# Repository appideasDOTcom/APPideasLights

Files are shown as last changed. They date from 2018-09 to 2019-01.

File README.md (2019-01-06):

This is code that was written to accompany a custom-built WiFi controller for 5050SMD LED light strips. The Instructable that shows you how to build the hardware is here:
https://www.instructables.com/id/Easier-WiFi-LED-Light-Strip-Controller/
The APPideas article that covers start-to-finish instructions is available here:
https://appideas.com/the-appideas-wifi-controller-for-led-light-strips/

The Instructables article and the writing at APPideas are nearly identical, but are organized differently. The APPideas write-up is more likely to be kept up-to-date.

An Instructables article that covers version 9 (an older version) of the hardware is here:
https://www.instructables.com/id/WiFi-LED-Light-Strip-Controller/

The arduino directory contains code to be uploaded to an ESP8266-12E development board. Directions for loading the Arduino code are available at the links above. If you built hardware version 9 or earlier (anything prior to the "Easier" WiFi controller article), you will need to checkout the Arduino code from the alt/v9Hardware branch. Alternatively, you can manually change the Arduino code to adjust the pin assignments for that version of the PCB.

The resources directory contains the license file, files for CNC routers and 3D printers, and Fritzing, Eagle and Fusion 360 documents. V10 folders contain current files. V9 and previous, as well as Fritzing files are for legacy versions of the hardware.

The mobile-app directory has a React Native project, which produced native code for both Android and iOS.

## Mobile app installation
**Install the current public version from an app store**
The easiest way to install the app is through your device's app store. Here are the links:
Android: https://play.google.com/store/apps/details?id=com.appideas.appideaslights
iOS: https://itunes.apple.com/us/app/appideas-lights/id1440833432?ls=1&mt=8

**Install the latest development version from source code**
This will only work if you have React Native setup for development. Instructions are available here: https://facebook.github.io/react-native/docs/getting-started.html
Once React Native is setup for development, open a terminal and run these commands
```
mkdir app
cd app
git clone https://github.com/appideasDOTcom/APPideasLights.git ./
cd mobile-app/react-native/AppideasLights
npm install
```
To install for iOS, plug your device into your computer and:
```
react-native run-ios
```
To install for Android, plug your device into your computer and:
```
react-native run-android
```
If compiling or installation fails, run the last command again. This is expected behavior for a first build in React Native

## Using the mobile app

If your controller has not been configured to connect to your network, go into your device's WiFi settings and connect to the access point that is created by the ESP. It will begin with "appideas-" After connecting to the access point, open the app. Alternatively, open a web browser and go to http://192.168.4.1:5050/ Supply your network credentials and click CONNECT. Connect your mobile device to your network again, then close and re-open the app. Tap "+" to add a controller by IP address. Once the controller is added, the main screen of the app will have a button showing its IP address. Tap the button to see the controls. To change the name of the controller or to update the IP address, tap the Config button.

## Controlling lights from a web browser

The ESP8266 controller will respond to http requests to the following endpoints:
```
/ - Displays either the screen that allows you to provide WiFi credentials or a notice that you are already connected
/connect - This only accepts POST data from the root node. Nothing useful will be gained by accessing it directly
/network-status - Get the device's network info in a JSON-encoded string
/status - Get the status of each set of lights in a JSON-encoded string
/rollcall - Verify that the device is responding in a known manner
/control - Control a set of lights. Possible GET parameters are: 
p: 'position' Accepts 'first' or 'second'
c: 'color' Accepts 'red' 'green' 'blue' 'white' or 'all'
l: 'level' Accepts any integer between 0 (off) and 100 (100% power)
```

Here's an example call to the controller:
```
http://10.0.42.241:5050/control?p=first&c=red&l=100
```

The feature/patternLoops branch contains two more endpoints that have no access in the app (yet), but if you want to check out that branch and upload the Arduino code to your ESP board, you may also use these endpoints:
```
/multiset - Set the values of all LEDS (red, green, blue and white) with a single network request
/pattern - Run a pattern, such as strobe or color changes on a timer
```

See issue #12 (Programmable patterns) and issue #16 (Save colors).

## Misc

I have written a crap-ton of mobile apps, but this is my first in React Native. It is functional, but not written with best practices. A majority of the items on the Issues list are related to that fact. If you are an experienced React Native developer and wouldn't mind offering a few hours to refactor this code before the codebase grows to be large, that would be awesome. Issue #1 is the core of it all.

Check out part 1 of this Instructable series. It's about making custom PCBs on a CNC router:

https://www.instructables.com/id/Custom-PCBs-on-a-CNC-Router/

If you have a CNC router this will come in handy for making a custom WiFi constroller.

## License

This software is available under a GPLv3 license. A copy of the license is in resources/gpl/

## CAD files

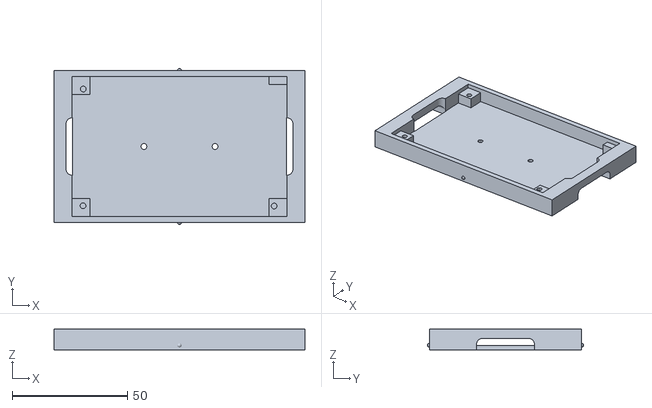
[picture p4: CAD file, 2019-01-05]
resources/3DPrinter/V10/3DPrinter-Electronics_mount_base-V10.stl
108.8 x 67.8 x 9.00

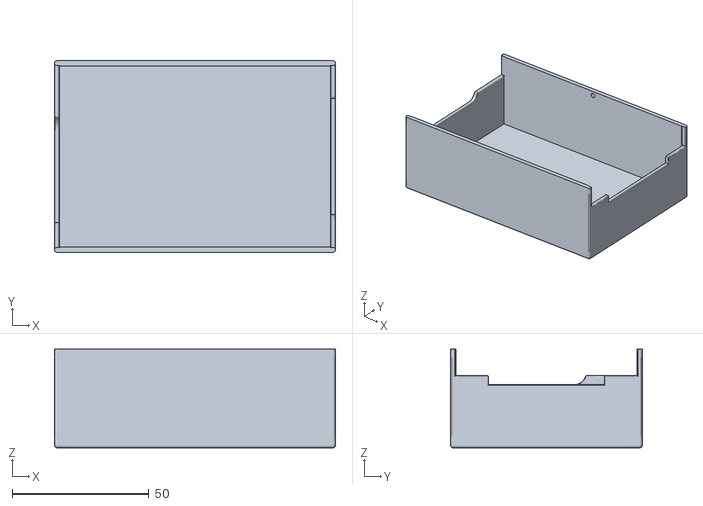
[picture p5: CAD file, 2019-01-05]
resources/3DPrinter/V10/3DPrinter-Electronics_mount_lid-V10.stl
102.6 x 70.0 x 36.1

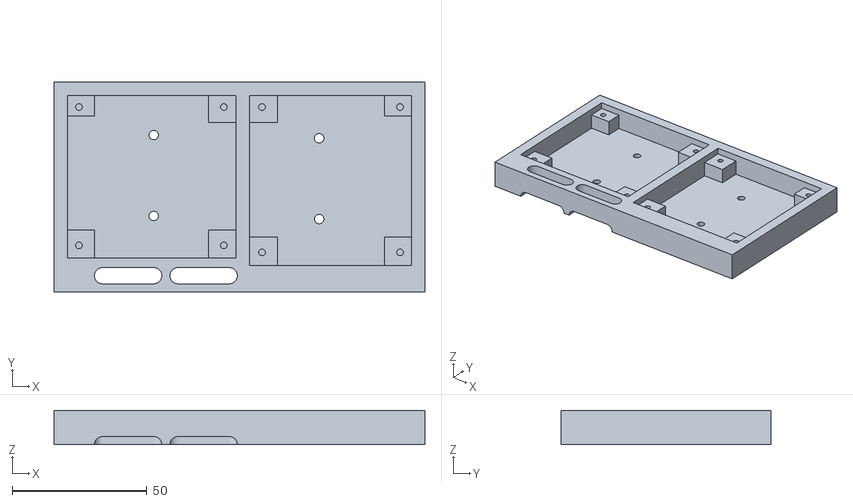
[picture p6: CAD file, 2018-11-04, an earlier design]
resources/3DPrinter/V9/3DPrinter-Electronics_mount-V9.stl
137.6 x 77.8 x 12.7

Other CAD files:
resources/3DPrinter/V10/3DPrinter-Electronics_mount-Fusion360.f3d
resources/3DPrinter/V9/Electronics V9 case.f3d

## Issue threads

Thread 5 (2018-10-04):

Catch network errors

appideasDOTcom, 2018-10-04:
We're not currently wrapping all network calls in try/catch, and there can be app crashes

appideasDOTcom, 2018-10-28:
Fixed with commit 5267d98

Closed 2018-10-28.

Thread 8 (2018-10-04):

Need to detect network state on wake and handle changes

appideasDOTcom, 2018-10-04:
When the app wakes from sleep, it needs to determine whether it is on the 192.168.4.* network and send the user to the appropriate screen

The failure to do so is classified as a bug because switching to/from the private network currently requires for the app to be completely killed and restarted.

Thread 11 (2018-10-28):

Get and set light status on control screen render

appideasDOTcom, 2018-10-28:
When the control screen renders, all the controls are set by default to "all the way on."

An http request to /status will supply a json string with the currently known status of the lights. This should be used to set the controls on initial screen rendering.

appideasDOTcom, 2018-10-29:
Fixed with commit ca2654a

Closed 2018-10-29.

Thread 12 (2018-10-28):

Programmable patterns

appideasDOTcom, 2018-10-28:
There needs to be a way to set a pattern (e.g. changing colors, pulsing, strobe, etc.) on the phone/external device, send the pattern to the controller, and have it continue the pattern without network interactions from the phone/device.

appideasDOTcom, 2018-11-14:
The beginnings of this feature have been committed (untested on actual lights) into the features/patternLoops branch.

This is working at a basic level on the Arduino device, although I will need to work out cross-dissolves for transitions.

It's not terribly useful until the app can control it, but if you want to try it out, point a web browser to:
http://<ip address of controller>:5050/pattern?p=first&d=3000&t=333&c=[100,0,0,0],[0,100,0,0],[0,0,100,0]

That will give you a red-green-blue pattern with 3 seconds for each color and a 1/3 second transition.

Also in this branch is a new endpoint of /multiset, which allows you to set all of the light values on a string at once (saving network requests). An example request is:
http://<ip address of controller>:5050/multiset?p=first&c=100,0,0,0

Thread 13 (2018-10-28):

Switch to Nodes screen after WiFi connect

appideasDOTcom, 2018-10-28:
After the WiFi connection on the ESP8266. the app is left in a state of confusion and has to be stopped and restarted after the phone/device device connects back to the target network before the screen that allows one to add nodes will appear.

The app should detect the network change, which will happen automatically in most cases, and automatically switch to the Nodes screen.

The current workarounds are:
1. Stop and restart the app after configuring the ESP8266 to connect to the home network, or
2. Configure the ESP8266 through a web browser at http://192.168.4.1:5050 before opening the app

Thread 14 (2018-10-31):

Redraw Nodes screen on rotate

appideasDOTcom, 2018-10-31:
On the Nodes screen (contains the list of controllers), when the screen rotates from landscape to portrait, items correctly rearrange on the screen. When the screen rotates from portrait to landscape, the available width does not adjust and the buttons remain centered with wide left and right margins.

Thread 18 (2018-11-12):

Arduino - Possible race condition

appideasDOTcom, 2018-11-12:
I have noticed that, on controllers that are far away from my WiFi router and have a poor WiFi signal, there are times when I will set a light's colors, watch the colors change successfully, leave that controller's screen, come back into the controller's screen of controls, and one of the sliders is set to an incorrect value. I verified that http://<ip_address>:5050/status returned the wrong value.

I have only noticed this behavior on devices that have a poor WiFi signal, and I cannot reproduce it at will. I believe that there is a race condition on the Arduino side between changing the values of the pins and changing the values stored in the status array, and it appears to be affected by network lag.

My assessment of the cause is only speculation based on my observation of the symptoms at this point.

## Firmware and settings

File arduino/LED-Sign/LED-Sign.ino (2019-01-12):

#include <ESP8266WiFi.h>
#include <ESP8266mDNS.h>
#include <WiFiUdp.h>
#include <ESP8266WebServer.h>
#include <WiFiClient.h>
#include <ArduinoJson.h>
#include <EEPROM.h>
#include <ArduinoOTA.h>

/**
 * A sketch to control two strings of RGBW LED lights from one ESP8266.
 * 
 * This creates its own wireless access point with an SSID beginning with "appideas-"
 *   that you need to connect to for configuring this device to connect to your network
 *   
 * For complete assembly and usage information, visit this Instructable:
 * https://www.instructables.com/id/Wifi-Led-Light-Strip-Controller/
 * 
 * @author costmo
 * @since  20180902
 */

// Setup a wireless access point so the user can be prompted to connect to a network
String  ssidPrefix = "appideas-";
int serverPort = 5050;
String ssid = "";
String softIP  = "";
bool wifiConnected = false;
const int MAX_WIFI_RETRIES = 60; // The maximum number of times we'll try connecting to WiFi before reverting to AP mode

// Setup NTP parameters for syncing with network time
const int TIMEZONE_OFFSET = 3600; // Number of seconds in an hour
int inputTimezoneOffset = 0; // Offset from UTC - will be input by the user
const char* ntpServerName = "time.nist.gov"; // NTP server to use
const int checkInterval = 60 * 30; // how often (in seconds) to query the NTP server for updates (30 minutes)
// NTP parameters that probably shouldn't be changed
unsigned int localPort = 2390;      // local port to listen for UDP packets
IPAddress timeServerIP; // time.nist.gov NTP server address
const int NTP_PACKET_SIZE = 48; // NTP time stamp is in the first 48 bytes of the message
byte packetBuffer[ NTP_PACKET_SIZE]; //buffer to hold incoming and outgoing packets
// A UDP instance to let us send and receive packets over UDP
WiFiUDP udp;

// For reference (pin mapping for ESP8266-12E):
// D0/GPIO16      = 16;
// D1/GPIO5       = 5;
// D2/GPIO4       = 4;
// D3/GPIO0       = 0;

// D4/GPIO2       = 2;

// D5/GPIO14      = 14;
// D6/GPIO12      = 12;
// D7/GPIO13      = 13;
// D8/GPIO15      = 15;


// Pin mapping for the first string of lights. Pins D0 - D3
#define WHITE_LED_FIRST     16
#define BLUE_LED_FIRST      5
#define RED_LED_FIRST       4
#define GREEN_LED_FIRST     0

// Second string of lights. Pins D5 - D8
#define WHITE_LED_SECOND     14
#define BLUE_LED_SECOND      12
#define RED_LED_SECOND       13
#define GREEN_LED_SECOND     15

int maxBrightness = 1024;
int offBrightness = 0;

int status = WL_IDLE_STATUS;
IPAddress ip;

ESP8266WebServer server( serverPort );

// Status variables
// Temporary holding for current values
int currentR = 0;
int currentG = 0;
int currentB = 0;
int currentW = 0;

// holding for current values on first and second string of lights
int currentRFirst = 0;
int currentGFirst = 0;
int currentBFirst = 0;
int currentWFirst = 0;

int currentRSecond = 0;
int currentGSecond = 0;
int currentBSecond = 0;
int currentWSecond = 0;

// Global time variables
String fullTime = String( "" );
String humanTime = String( "" );
int intTime = 0;
int currentHour = 0;
int currentMinute = 0;
int currentSecond = 0;
int currentMeridiem = 0;

// Values saved to EEPROM for persistent storage of settings
struct StoredSettings
  {
    char ssid[128];
    char pass[128];
    int offset = 0;
  } romSettings;

/**
 * Run on device power-on
 * 
 * @author costmo
 * @since  20180902
 */
void setup() 
{
  Serial.begin( 57600 );
  delay( 100 );

  // Prepare the pins to fire
  pinMode( WHITE_LED_FIRST, OUTPUT );
  pinMode( BLUE_LED_FIRST, OUTPUT );
  pinMode( RED_LED_FIRST, OUTPUT );
  pinMode( GREEN_LED_FIRST, OUTPUT );

  pinMode( WHITE_LED_SECOND, OUTPUT );
  pinMode( BLUE_LED_SECOND, OUTPUT );
  pinMode( RED_LED_SECOND, OUTPUT );
  pinMode( GREEN_LED_SECOND, OUTPUT );

  // uncomment the line below to erase your stored network credentials when the device powers on
  //wipeSettings();
  
  // Check to see if we have stored network credentials already
  if( !haveNetworkCredentials() )
  {
    // Start the local access point
    wipeSettings();
    startSoftAP();
  }
  else // Attempt to connect to the local network based on stored credentials
  {
    StoredSettings deviceSettings = getStoredSettings();
    connectToWifi( String( deviceSettings.ssid ), String( deviceSettings.pass ) );
  }
  // Start the web server and get ready to handle incoming requests
  startWebServer();

  // turn all the lights on when the ESP first powers on
  turnOn( "first" );
  turnOn( "second" );
}

/**
 * Whether or not we have stored network credentials. Will return false of the stored SSID is "appideas-changeme"
 * 
 * @return bool
 * @author costmo
 * @since  20180929
 */
bool haveNetworkCredentials()
{
  StoredSettings deviceSettings = getStoredSettings();

  // < 2 to catch empty string
  if( deviceSettings.ssid == NULL || 
      sizeof( deviceSettings.ssid ) < 2 || 
      String( deviceSettings.ssid ).equals( "appideas-changeme" ) )
  {
    return false; 
  }

  return true;
}

/**
 * Turn all lights to max brightness
 * 
 * @return void
 * @author costmo
 * @since  20180902
 * @param  String   whichPosition     first|second
 */
void turnOn( String whichPosition ) 
{ 
  setColorToLevel( whichPosition, "all", maxBrightness );
}

/**
 * Turn all lights off
 * 
 * @return void
 * @author costmo
 * @since  20180902
 * @param  String   whichPosition     first|second
 */
void turnOff( String whichPosition ) 
{
  setColorToLevel( whichPosition, "all", offBrightness );
}

/**
 * Set a color at a position to a specific level between 0 and 1024
 * 
 * @return void
 * @author costmo
 * @since  20180902
 * @param  String   whichPosition     first|second
 * @param  String   color             red|green|blue|white|all
 * @param  intng    level             0 - 1024
 */
void setColorToLevel( String whichPosition, String color, int level ) 
{ 
  int redPin = RED_LED_FIRST;
  int greenPin = GREEN_LED_FIRST;
  int bluePin = BLUE_LED_FIRST;
  int whitePin = WHITE_LED_FIRST;

  if( whichPosition == "second" )
  {
    redPin = RED_LED_SECOND;
    greenPin = GREEN_LED_SECOND;
    bluePin = BLUE_LED_SECOND;
    whitePin = WHITE_LED_SECOND;
  }
  
  if( color == "red" )
  {
    analogWrite( redPin, level );
    currentR = level;
  }
  if( color == "green" )
  {
    analogWrite( greenPin, level );
    currentG = level;
  }
  if( color == "blue" )
  {
    analogWrite( bluePin, level );
    currentB = level;
  }
  if( color == "white" )
  {
    analogWrite( whitePin, level );
    currentW = level;
  }
  if( color == "all" )
  {
    analogWrite( redPin, level );
    analogWrite( greenPin, level );
    analogWrite( bluePin, level );
    analogWrite( whitePin, level );
    currentR = level;
    currentG = level;
    currentB = level;
    currentW = level;
  }

  if( whichPosition == "second" )
  {
    currentRSecond = currentR;
    currentGSecond = currentG;
    currentBSecond = currentB;
    currentWSecond = currentW;
  }
  else
  {
    currentRFirst = currentR;
    currentGFirst = currentG;
    currentBFirst = currentB;
    currentWFirst = currentW;
  }
}

/**
 * Run while the sketch is active
 * 
 * @return void
 * @author costmo
 * @since  20180902
 */
void loop() 
{
  // Listen for API requests
  server.handleClient();
  
  // Listen for OTA updates
  ArduinoOTA.handle();
}

/**
 * Handler for requests to "/"
 * 
 * This should only provide the interface for logging into a network or show a "you are already connected" message
 * 
 * @return void
 * @author costmo
 * @since  20180913
 */
void handleRoot()
{
  if( !wifiConnected )
  {
    Serial.println( "Connecting" );
    server.send( 200, "text/html", connectionHtml() );
  }
  else
  {
    Serial.println( "Already connected" );
    server.send( 200, "text/html", connectedHtml() );
  }
  delay( 100 );
}

/**
 * Handler for requests to "/rollcall"
 * 
 * This is here so an app can easily scan a network and find nodes
 * 
 * @return void
 * @author costmo
 * @since  20180913
 */
void handleRollCall()
{
  String sendValue = "";
  StaticJsonBuffer<1024> jsonBuffer;
  JsonObject& root = jsonBuffer.createObject();
  root["status"] = "present";
  root["mac"] = WiFi.macAddress();
  root.printTo( sendValue );
  
  server.send( 200, "text/html", sendValue );
}

/**
 * Sends a blank JSON string
 * 
 * This is used for network interactions in which the requestor is expecting a JSON response, but for the 
 *   sake of efficiency, we do not want to add extra processing to generate something meaningful
 * 
 * @return void
 * @author costmo
 * @since  20180913
 */
void sendBlank()
{
  String sendValue = "";
  StaticJsonBuffer<32> jsonBuffer;
  JsonObject& root = jsonBuffer.createObject();
  root[""] = "";
  root.printTo( sendValue );
  
  server.send( 200, "text/html", sendValue );
}

/**
 * Handler for requests to "/connect" Connects to the local wifi network, establishes an NTP connection and synchronizes the time
 * 
 * connectToWifi() and getTime() do all the actual work
 * 
 * @see connectToWifi
 * @return void
 * @author costmo
 * @since  20180913
 */
void handleConnect()
{
  String hardSSID = server.arg( "ssid" );
  String hardPassword = server.arg( "password" );
  int tmpInputTimezoneOffset = server.arg( "timezone" ).toInt();

  if( tmpInputTimezoneOffset != 0 )
  {
    inputTimezoneOffset = tmpInputTimezoneOffset;
  }

  saveSettings( hardSSID, hardPassword, inputTimezoneOffset );

  if( !wifiConnected )
  {
    ssid = hardSSID;
    connectToWifi( ssid, hardPassword );
  }

  String newIp = WiFi.localIP().toString();
  server.send( 200, "text/html", redirect( newIp ) ); // Redirecting really doesn't work since the device will already be on a different network. We can still try, tough.

  // Get and show the time
  Serial.println( "Starting UDP" );
  udp.begin( localPort );
  fullTime = getTime();
  timeToVars();
  Serial.println( "Current time: " + humanTime );
  
  server.send( 200, "text/html", connectedHtml() );
  Serial.println( "Connected to WiFi" );
  delay( 100 );
}

/**
 * Start the local access point
 * 
 * @return void
 * @author costmo
 * @since  20180913
 */
void startSoftAP()
{
  String mac = WiFi.macAddress();
  String macPartOne = mac.substring( 12, 14 );
  String macPartTwo = mac.substring( 15 );
  ssid = ssidPrefix + macPartOne + macPartTwo; // "appideas-" followed by the last 4 characters of the device MAC address
  
  WiFi.softAP( ssid.c_str() );
  softIP = WiFi.softAPIP().toString();
 
  Serial.println( getSoftAPStatus() );
}

/**
 * Handler for requests to "/network-status"
 * 
 * Sends a JSON encoded string to the web browser containing the device's network status
 * 
 * @return void
 * @author costmo
 * @since  20180913
 */
void handleNetworkStatus()
{
   server.send( 200, "text/html", getNetworkStatus() );
}

/**
 * Handler for requests to "/status"
 * 
 * Sends a JSON encoded string to the web browser containing the status device's lights
 * 
 * @return void
 * @author costmo
 * @since  20180913
 */
void handleStatus()
{
   server.send( 200, "text/html", getStatus() );
}

/**
 * Define the endpoints for a tiny API server for receiving and handling requests and start the web server
 * 
 * @return void
 * @author costmo
 * @since  20180902
 */
void startWebServer()
{
  server.on( "/", handleRoot );
  server.on( "/connect", handleConnect );
  server.on( "/network-status", handleNetworkStatus );
  server.on( "/status", handleStatus );
  server.on( "/control", handleControl );
  server.on( "/rollcall", handleRollCall );
  server.begin();
}

/**
 * Connect to a wifi network and print the status
 * 
 * @return void
 * @author costmo
 * @since  20180902
 */
void connectToWifi( String wifiSSID, String wifiPassword )
{
  int attemptCount = 0;
  
  Serial.print( "Connecting to " );
  Serial.println( wifiSSID );
  
  WiFi.mode( WIFI_STA );
  WiFi.begin( wifiSSID.c_str(), wifiPassword.c_str() );

  while( WiFi.status() != WL_CONNECTED )
  {
      delay( 500 ); // delay one-half second between retries
      Serial.print( "." );

      // Reset EEPROM values and go into AP mode if the connection hasn't been established for a period of time. Default: 30 seconds
      if( attemptCount > MAX_WIFI_RETRIES )
      {
        wipeSettings();
        startSoftAP();
        return;
      }
      attemptCount++;
  }
  Serial.println( "." );
  Serial.println( "Connected" );
  wifiConnected = true;
  printWifiStatus();
  
  // Get over-the-air updates setup and ready
  initOta();
}

/**
 * Print the current IP address
 * 
 * @return void
 * @author costmo
 * @since  20180902
 */
void printWifiStatus() 
{
  // print your WiFi IP address:
  ip = WiFi.localIP();
  Serial.print( "IP Address: " );
  Serial.println( ip );
}
 
/**
 * Gets the current level (0 - 1024) for the given color and position
 * 
 * @return int
 * @author costmo
 * @since  20180902
 * @param  String   whichPosition     first|second
 * @param  String   color             red|green|blue|white|all
 */
int getLevelForColor( String whichPostiion, String color )
{
  
  if( color == "red" )
  {
    if( whichPostiion == "second" )
    {
      return currentRSecond;
    }
    else
    {
      return currentRFirst;
    } 
  }
  else if( color == "green" )
  {
    if( whichPostiion == "second" )
    {
      return currentGSecond;
    }
    else
    {
      return currentGFirst;
    }
  }
  else if( color == "blue" )
  {
    if( whichPostiion == "second" )
    {
      return currentBSecond;
    }
    else
    {
      return currentBFirst;
    }
  }
  else if( color == "white" )
  {
    if( whichPostiion == "second" )
    {
      return currentWSecond;
    }
    else
    {
      return currentWFirst;
    }
  }
  else
  {
    return 0;
  }
}

// 
/**
 * Gets the current ratio (0.0 - 1.0) for the given color and position
 * 
 * @return float
 * @author costmo
 * @since  20180902
 * @param  String   whichPosition     first|second
 * @param  String   color             red|green|blue|white|all
 */
float getRatioForColor( String whichPosition, String color )
{
  int  currentValue = getLevelForColor( whichPosition, color );
  return (float) ((float)currentValue / (float)1024);
}

/**
 * Handles API requests to control lights
 * 
 * @return void
 * @author costmo
 * @since  20180902
 */
void handleControl()
{
  // parse the incoming request and do the work
  // p = "position" = first|second
  // c = "color" = red|green|blue|white|all
  // l ="level" = 0-100

  String lightPosition = server.arg( "p" );
  String lightColor = server.arg( "c" );
  int lightLevel = server.arg( "l" ).toInt();

  String requestPosition = "first";
  String requestColor = lightColor;
  float ratio = ((float)lightLevel / (float)100);
  int requestLevel = ceil( ratio * maxBrightness );

  if( lightPosition.equals( "second" ) )
  {
    requestPosition = "second";
  }

  if( requestColor == "all"  )
  {
    setColorToLevel( requestPosition, "red", requestLevel );
    setColorToLevel( requestPosition, "green", requestLevel );
    setColorToLevel( requestPosition, "blue", requestLevel );
    setColorToLevel( requestPosition, "white", requestLevel );
  }
  else
  {
    setColorToLevel( requestPosition, requestColor, requestLevel );
  }
  delay( 50 ); // give the web server a small amount of time to buffer and send
  // server.send( 200, "text/html", getStatus() );
  sendBlank();
  server.send( 200, "text/html", "" ); // see if we can improve response times a little bit
}

/**
 * Get the current time from an NTP server
 * 
 * @return String
 * @author costmo
 * @since  20180902
 */
String getTime()
{
  
  //Serial.println( "Getting time" );
  String returnValue = String();

  //get a random server from the pool
  WiFi.hostByName( ntpServerName, timeServerIP );

  sendNTPpacket( timeServerIP ); // send an NTP packet to a time server
  // wait to see if a reply is available
  delay( 2000 );
  
  int cb = udp.parsePacket();
  // loop until we have a good connection
  while( !cb ) 
  {
    //Serial.println( "Problem reading from NTP server. Retrying in 10 seconds..." );
    delay( 10000);
    //Serial.println( "Trying again..." );
    cb = udp.parsePacket();
  }

    // We've received a packet, read the data from it
    udp.read( packetBuffer, NTP_PACKET_SIZE ); // read the packet into the buffer

    //the timestamp starts at byte 40 of the received packet and is four bytes,
    // or two words, long. First, esxtract the two words:

    unsigned long highWord = word( packetBuffer[40], packetBuffer[41] );
    unsigned long lowWord = word( packetBuffer[42], packetBuffer[43] );
    // combine the four bytes (two words) into a long integer
    // this is NTP time (seconds since Jan 1 1900):
    unsigned long secsSince1900 = highWord << 16 | lowWord;

    // now convert NTP time into everyday time:
    // Unix time starts on Jan 1 1970. In seconds, that's 2208988800:
    const unsigned long seventyYears = 2208988800UL;
    // subtract seventy years:
    unsigned long epoch = secsSince1900 - seventyYears;

    epoch = epoch + (TIMEZONE_OFFSET * (inputTimezoneOffset + 1));

    int hour = ((epoch  % 86400L) / 3600);
    int minute = ((epoch  % 3600) / 60);
    int second = (epoch % 60);
    
    // make a 12 hour clock
    bool isPM = false;
    if( hour >= 12 )
    {
      isPM = true;
      if( hour > 12 )
      {
        hour = hour - 12;
      }
    }
    if( hour == 0 )
    {
      hour = 12;
    }
    
    returnValue = String( hour );
    returnValue = String( returnValue + " " );
    returnValue = String( returnValue + minute );
    returnValue = String( returnValue + " " );
    returnValue = String( returnValue + second );
    
    if( isPM )
    {
      returnValue = String( returnValue + " 1" );
    }
    else
    {
      returnValue = String( returnValue + " 0" );
    }

    humanTime = String( hour );
    humanTime = String( humanTime + ":" );
    humanTime = String( humanTime + minute );
    humanTime = String( humanTime + ":" );
    humanTime = String( humanTime + second );
    if( isPM )
    {
      humanTime = String( humanTime + " PM" );
    }
    else
    {
      humanTime = String( humanTime + " AM" );
    }

  return returnValue;
}

/**
 * Writes all time components to member variables for easier parsing and display.
 * 
 * This should only be run immediately following a call to getTime()
 * 
 * TODO: Make minutes and seconds < 10 zero-padded
 * 
 * @return void
 * @author costmo
 * @since  20180902
 */
void timeToVars()
{
  int separator1 = fullTime.indexOf( ' ' );
  int separator2 = fullTime.indexOf( ' ', (separator1 + 1) );
  int separator3 = fullTime.indexOf( ' ', (separator2 + 1) );

  String hourAsString = fullTime.substring( 0, separator1 );
  String minuteAsString = fullTime.substring( separator1, separator2 );
  String secondAsString = fullTime.substring( separator2, separator3 );
  String meridiemAsString = fullTime.substring( separator3 );


  currentHour = hourAsString.toInt();
  currentMinute = minuteAsString.toInt();
  int second = secondAsString.toInt();

  currentSecond = second;
  if( currentSecond >= 60 )
  {
    currentSecond = (currentSecond % 60);
    currentMinute += 1;
  }

  if( currentMinute >= 60 )
  {
    currentMinute = (currentMinute % 60);
    currentHour += 1;
  }

  if( currentHour >= 12 )
  {
    currentMeridiem = 1;
    currentHour = (currentHour % 12);
    if( currentHour == 0 )
    {
      currentHour = 11;
    }
    currentHour += 1;
  }
  else
  {
    currentMeridiem = 0;
  }

  if( currentHour < 12 && currentMeridiem > 0 )
  {
    currentHour = currentHour + 12;
  }

  String stringMinute = String( currentMinute );
  if( currentMinute < 10 )
  {
    stringMinute = "0" + stringMinute;
  }

  String timeString = String( currentHour );
  timeString = timeString + stringMinute;
  intTime = timeString.toInt();
}

 /**
 * Send an NTP request to the time server at the given address
 * 
 * @return long
 * @author costmo
 * @since  20180902
 * @param  IPAddress    address       A pointer to the IP address of the NTP server
 */
unsigned long sendNTPpacket( IPAddress& address )
{
  //Serial.println("sending NTP packet...");
  // set all bytes in the buffer to 0
  memset(packetBuffer, 0, NTP_PACKET_SIZE);
  // Initialize values needed to form NTP request
  // (see URL above for details on the packets)
  packetBuffer[0] = 0b11100011;   // LI, Version, Mode
  packetBuffer[1] = 0;     // Stratum, or type of clock
  packetBuffer[2] = 6;     // Polling Interval
  packetBuffer[3] = 0xEC;  // Peer Clock Precision
  // 8 bytes of zero for Root Delay & Root Dispersion
  packetBuffer[12]  = 49;
  packetBuffer[13]  = 0x4E;
  packetBuffer[14]  = 49;
  packetBuffer[15]  = 52;

  // all NTP fields have been given values, now
  // you can send a packet requesting a timestamp:
  udp.beginPacket(address, 123); //NTP requests are to port 123
  udp.write(packetBuffer, NTP_PACKET_SIZE);
  udp.endPacket();
}

/**
 * Gets the network status and returns info as a JSON-encoded string
 * 
 * @return String
 * @author costmo
 * @since  20180913
 */
String getNetworkStatus()
{
  String returnValue = "";

  StaticJsonBuffer<1024> jsonBuffer;
  JsonObject& root = jsonBuffer.createObject();
  if( wifiConnected )
  {
    root["soft"] = "disconnected";
    root["hard"] = "connected";
    root["ip"] = WiFi.localIP().toString();
  }
  else
  {
    root["soft"] = "connected";
    root["hard"] = "disconnected";
    root["ip"] = softIP;
  }
  root["ssid"] = ssid;

  root.printTo( returnValue );

  return returnValue;
}
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

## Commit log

2018-09-02 File structure corrected by Arduino IDE
    [LED-Sign.ino]
2018-09-13 - Adding SoftAP capabilities so users don't have to modify code to connect to a home network - Remove OTA features since the device won't have network credentials on power-on
    [LED-Sign.ino]
2018-09-16 - Functioning Controls screen - Updated Arduino code for debugging
2018-09-17 Improved response times from the Arduino and cleaner handling in the app
2018-09-29 Re-introduce over-the-air updates since we can now connect to a proper WiFi network during power-on
2018-10-03 - Switch to Realm for database access - Allow multiple controllers to be added
2018-10-05 Commit existing Fritzing and FlatCAM resources
    [01-MCU_board.fzz, 02-FET_board.fzz, breadboard_view-01.fzz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]
2018-10-09 Adding Fritzing files to the repository
    [01-MCU_board_voltageregulator_copperBottom.gbl, 01-MCU_board_voltageregulator_maskBottom.gbs, 02-FET_board_copperBottom.gbl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]
2018-10-29 Better default state for on/off toggle. Remove unused "Scan network" button.
2018-11-04 Adding V9 electronics files & 3D printed case. Arrange files.
    [3DPrinter-Electronics_mount-V8.stl, 3DPrinter-Electronics_mount-V9.stl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]
2018-11-04 Fix alignment of through-holes
    [copper_bottom.gbr, drills.xln, soldermask_bottom.gbr]
2018-11-04 Adding Fusion360 files for 3D printed cases
    [Electronics V8 case.f3d, Electronics V9 case.f3d]
2018-11-05 Replace V8 electronics with V9
    [01-MCU_board.fzz, 02-FET_board.fzz, 3DPrinter-Electronics_mount-V8.stl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]
2018-11-05 Better alignment on FET board
    [copper_bottom.gbr, drills.xln, soldermask_bottom.gbr]
2018-12-13 Corrected pin numbers after testing
    [LED-Sign.ino]
2018-12-29 Re-corrected pin assignment after discovering that a cheap-o light manufacturer mixed up their wires and I assumed they were correct.
    [LED-Sign.ino]
2019-01-05 Adding version 10 gerber, Eagle and STL files
    [3DPrinter-Electronics_mount_base-V10.stl, 3DPrinter-Electronics_mount_lid-V10.stl]
2019-01-05 Add V10 Fusion 360 files for the electronics mount case
    [3DPrinter-Electronics_mount-Fusion360.f3d]
2019-01-05 Master branch switch back to using local jsbundle after development branch merge
2019-01-06 Switch back to development jsbundle
2019-01-12 Finally corrected Arduino pin mapping. Unfortunately, it is common for manufacturers to incorrectly wire their lights and mislabel their strips, so my initial pin mappings were off.
    [LED-Sign.ino]
